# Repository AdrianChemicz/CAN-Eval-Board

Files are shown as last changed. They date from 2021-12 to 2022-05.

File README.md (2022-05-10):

# CAN Evaluation Board

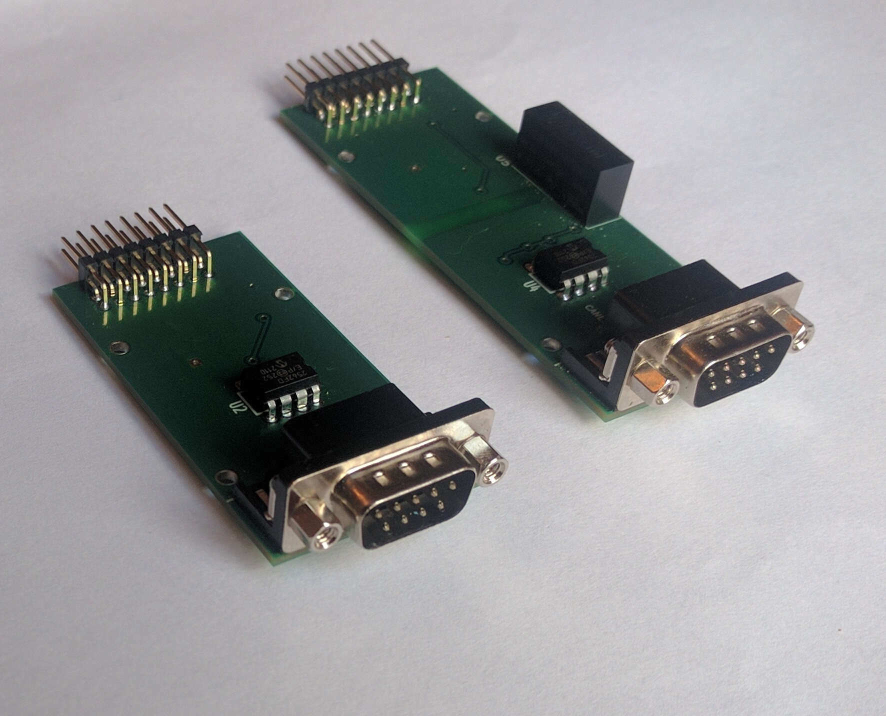
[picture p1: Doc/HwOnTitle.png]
Hardware on title
 <br />

CAN Evaluation Board is hardware project which provide evaluation board for CAN-FD. Evaluation board was prepared in two variant isolated and not isolated. Both variant use similar HW component like MCP2517FD and MCP2562FD chips. 

Device overview <br />

## 1.MCP2517FD

MCP2517FD is Microchip chip which work as SPI to CAN-FD converter. This chip provide also GPIO pins which can be configured via SPI and change state depending from situation like receive CAN message. Those GPIO pins was routed to connector CN1.<br /> 
On new design MCP2517FD chip is not recomended user should select MCP2518FD. Older driver should be compatible with this chip.

## 2.CAN transceiver

MCP2517FD chip to work with CAN network require CAN transceiver and for this purpose was chosen MCP2562FD chip in DIP8 package. Chip crisis cause that only this transceiver is available on market. This chip was optimaze for transfers up to 5 Mbps in CAN-FD mode.

## 3.Protection by isolation

Version of project which contain isolation to protect our system from high voltage on DB9 connector use DC/DC converter with galvanic separation to power CAN transceiver and optoisolation chip to separate CANTXD and CANRXD. As optoisolation was used MAX22245BAWA+ chip which add delay 43.7ns in worse case and allow to transmit signal with max transfer 25Mbps. Those parameters is very important because CAN controller during transmission via CANTX expect feeddback from transceiver on CANRX pin. Maximum delay between signal on pin CANTXD and CANRXD is equal 255ns. All things regarding optoisolation in CAN-FD systems was described in below document: <br />
[Meeting the Timing Requirements of CAN FD in Isolated CAN Systems for HEV/EVs](https://www.ti.com/lit/an/slla479/slla479.pdf) <br />

Delay on our system is also generated by PCB traces but this delay is very low (signal transmission speed is equal 6inch per ns). Equation about PCB signal delay is available on below page: <br />
[How to Calculate Trace Length from Time Delay Value for High-speed Signals](https://www.zuken.com/en/blog/how-to-calculate-trace-length-from-time-delay-value-for-high-speed-signals/) <br />

Worse case signal delay in our system was presented on below picture:
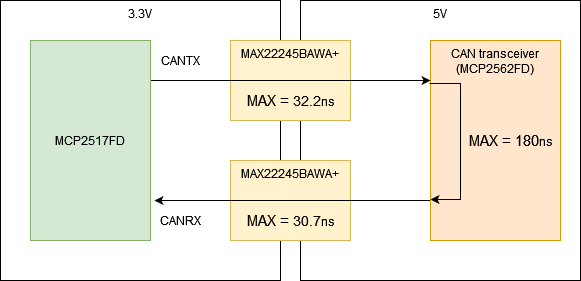
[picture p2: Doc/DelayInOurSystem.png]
Delay in our system
 <br />

In below table was presented typical and worse case signal propagation delay for all used electrical component.<br />
Electrical component | Typical propagation delay | Worse case propagation delay
------------ | ------------ | ------------
MAX22245BAWA+(Optoisolation chip) power from 3,3V | 23.4ns | 32.2ns
MAX22245BAWA+(Optoisolation chip) power from 5V | 22.6ns | 30.7ns
MCP2562FD(CAN transceiver) | 120ns | 180ns

Complete worse case propagation delay is equal:<br />
32.2ns + 30.7ns + 180ns = 242,9ns + small delay on traces which shouldn't exceed 1ns <br /><br />
In system was used two optoisolation chip instead one because selected chip transmit signal in one direction. Use bidirectional chip is very hard to find becauase chip crisis cause that many electrical component are unavailable on market. In project was used chip MAX22245BAWA+ which work only in single direction. Manufacturer Maxim Integrated offer similar chip but with bidirectional isolation this is marked as MAX22246BAWA+. Using this bidirectional chip PCB design will looks like better - one chip intead two.<br /><br />

To power chips on isolated part is used DC/DC converter with galvanic separation. In project was selected RFMM-0505S converter. This type of converter for correct operation require load on output so for this reason was used 470 ohm resistor(R3 on schematic).

## 4.Overal system design

On belew schematics was presented all parts of the system.

Version without optoisolation: <br />
Device without opto <br />
Version with optoisolation: <br />
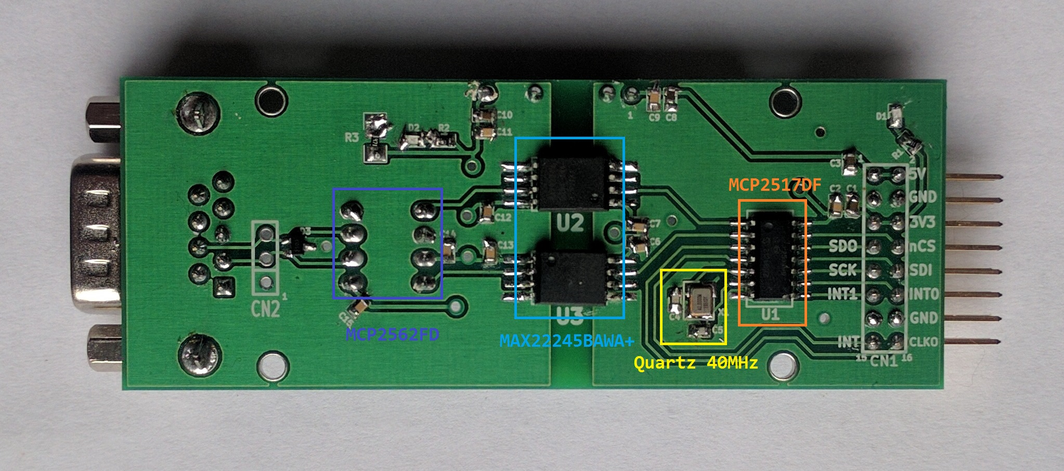
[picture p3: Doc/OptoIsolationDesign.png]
Device with opto
 <br />

On below pin header which is the same for two type of board with MCP2517FD chip exist two type of voltage input 3.3V and 5V. 3.3V input is used to power MCP2517FD chip and optoisolation module. 5V connector is used to power CAN transceiver. MCP2517FD chip and optoisolation module can correctly operate with 5V power suplly(MCP2517FD can operate in voltage range from 2,7V to 5,5Vs and MAX22245BAWA+ can operate in voltage range from 1,71V to 5,5V) so it mean that two power suply isn't necessary and can be reduced to single 5V power suply connected to 3V3 and 5V connectors. Connect 5V to 3V3 connector on board with MCP2517FD was tested on setup with LPC11U24 microcontroller and communication working correctly(CAN traffic was send correctly to bus). Used LPC11U24 during test was powered from 3,3V and work correctly with MCP2517FD because used microcontroller pins are 5V tolerant so communication will not damage microcontroler. 
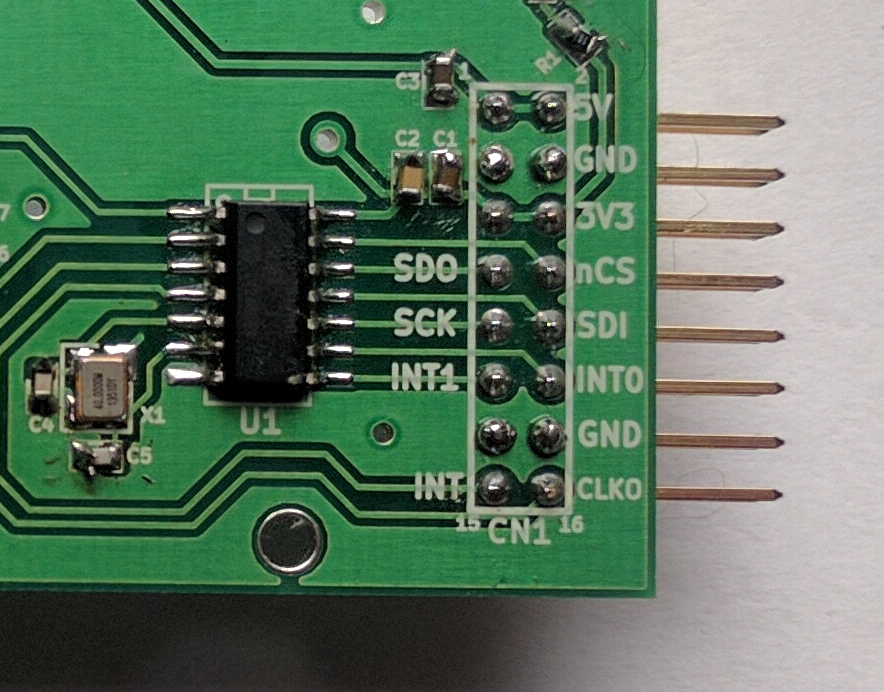
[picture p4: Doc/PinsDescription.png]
Pin header
 <br />

## 5.Project file

PCBs was designed in Kicad application and all files was added to appropriate project folders. In project folders also was added photos of PCB and PDF file with schematic. <br />
-board with optoisolation is available in below location: <br />
[CAN-FD optoisolated board](https://github.com/AdrianChemicz/CAN-Eval-Board/tree/main/CANFD_OptoIsolationBoardHardware) <br />
-board without optoisolation is available in below location: <br />
[CAN-FD board](https://github.com/AdrianChemicz/CAN-Eval-Board/tree/main/CANFD_BoardHardware) <br />

## 6.Software for MCP2517FD chip

### 6.1 Basic information
Microchip deliver example with library which can be very easly ported from microchip microcontroller to other microcontroller. From user perspective is only require to modify drv_spi.c file which contain access to SPI interface(only one file which depend from peripheral).

In drv_canfdspi_api.h header file we can find information "Subject to your compliance with these terms, you may use Microchip software and any derivatives exclusively with Microchip products." . According this paragraph I have doubt about legality usage of this library with MCP2517FD chip and NXP microcontrollers. Case was created on Microchip page and employee from Microchip answear that is only require use MCP2517xD chip with this driver and port to other microcontroller which belong to other manufacturer than microchip is legal.

Below I added links to microchip page with things for MCP2517FD chip: <br />
[-link to Microchip page with information about MCP2517FD](https://www.microchip.com/en-us/product/MCP2517FD) <br />
[-link to Microchip page with information about MCP2518FD which is recomended for new design](https://www.microchip.com/en-us/product/MCP2518FD) <br />
[-Link to source code example on Microchip page](https://ww1.microchip.com/downloads/en/DeviceDoc/MCP2517FD%20canfdspi%20API%20for%20SAMV71%20(v1.0).zip) <br /><br />
Complete port process of microchip library to other microcontroller require from user few steps and below all necessary things was described:<br />

1)From link section in this chapter please download SW example from mmicrochip page and copy "driver" directory from folder "MCP2517FD canfdspi API for SAMV71 (v1.0).zip\V71_CANFDSPI\V71_CANFDSPI" to new project directory.<br />
2)In \driver\spi\drv_spi.c modify below things:<br />
a)Modify function spi_master_init(void) which initialize microcontroller SPI port.<br />
a)modify function spi_master_transfer(...) which send data via microcontroller SPI port.<br />
c)modify #include section to keep only necessary things and include file with driver to used microcontroller.<br />
d)modify #define section to don't keep not used things.<br /><br />

In [SW directory](https://github.com/AdrianChemicz/CAN-Eval-Board/tree/main/SW)
 was provided examples for three LPC microcontrollers(MCP2517FD_ExampleFor_LPC111X, MCP2517FD_ExampleFor_LPC11UXX and MCP2517FD_ExampleFor_LPC82X). In those three examples most of code operate just on microchip API not on microntrollers peripherals. Provided code only use systick as timer which is common for all cortex-MX microcontrolers and can be very easy ported to other ARM microcontrollers. In those three provided example micirochip API is called from [MCP2517FD_ExampleFor_LPC111X.c](https://github.com/AdrianChemicz/CAN-Eval-Board/blob/main/SW/MCP2517FD_ExampleFor_LPC111X/src/MCP2517FD_ExampleFor_LPC111X.c), [MCP2517FD_ExampleFor_LPC11UXX.c](https://github.com/AdrianChemicz/CAN-Eval-Board/blob/main/SW/MCP2517FD_ExampleFor_LPC11UXX/src/MCP2517FD_ExampleFor_LPC11UXX.c) and [MCP2517FD_ExampleFor_LPC82X.c](https://github.com/AdrianChemicz/CAN-Eval-Board/blob/main/SW/MCP2517FD_ExampleFor_LPC82X/src/MCP2517FD_ExampleFor_LPC82X.c) files(single file per example). In provided examples is possible to prepare test of SPI interface without connected MPC2517FD chip. If physical connection with chip will be missing then SPI communication with chip will be not suspended by example. Using this feature in provided examples was added below code:
>#if 0 //SPI protocol debug code<br />
>	{<br />
>		uint8_t testedWritePayload[8] = {46, 5, 124, 119, 122, 9, 87, 234};<br />
>		uint8_t readPayload[8] = {0, 0, 0, 0, 0, 0, 0, 0};<br />
>		// Write data to RAM<br />
>		DRV_CANFDSPI_WriteByteArray(DRV_CANFDSPI_INDEX_0, cRAMADDR_START, testedWritePayload, 8);<br />
><br />
>		// Read data back from RAM<br />
>		DRV_CANFDSPI_ReadByteArray(DRV_CANFDSPI_INDEX_0, cRAMADDR_START, readPayload, 8);<br />
><br />
>		Nop();<br />
>	}<br />
>#endif<br />

Using this part of code user can verify that SPI work correctly by own SPI traffic with below log.<br /> 
Function DRV_CANFDSPI_WriteByteArray in debug code will cause that ganerated SPI traffic will be similar like this traffic below:
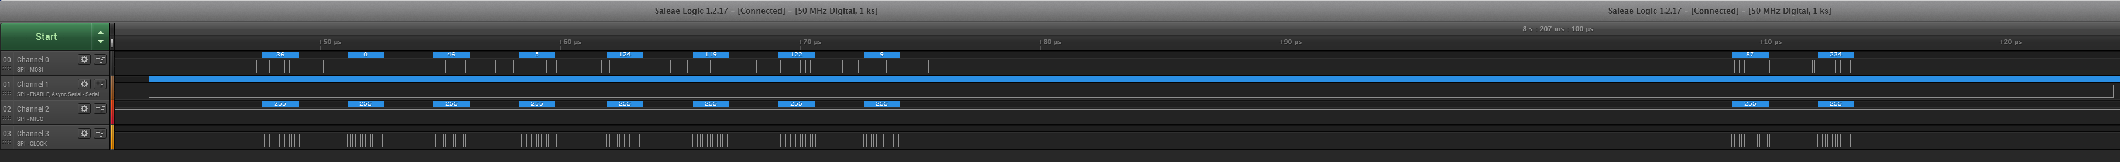
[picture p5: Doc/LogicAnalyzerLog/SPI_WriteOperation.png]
SPI write

Function DRV_CANFDSPI_ReadByteArray in debug code with correctly connected and configured MCP2517FD chip will cause that ganerated SPI traffic will be similar like this traffic below:
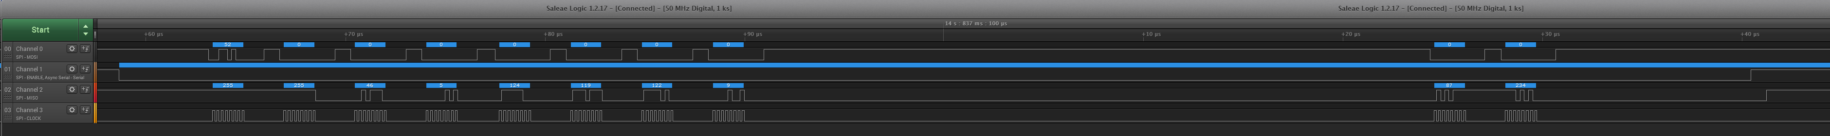
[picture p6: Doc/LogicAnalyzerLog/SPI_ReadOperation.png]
SPI read


Below was added SPI setting from Saleae logic analyzer used during decode data:
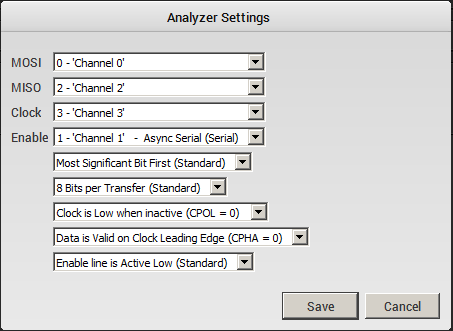
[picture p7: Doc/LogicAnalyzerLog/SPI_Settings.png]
SPI settings


In [directory with SPI screenshots](https://github.com/AdrianChemicz/CAN-Eval-Board/tree/main/Doc/LogicAnalyzerLog) was added log gather via Saleae logic analyzer in binary format and CSV file.

### 6.2 Code examples

In [SW directory](https://github.com/AdrianChemicz/CAN-Eval-Board/tree/main/SW) was provided few examples which can be directly imported to LPCXpresso. To setup complete working environment source code is not enough. To provide fully working environment is required microcontroller eval board connected to board with MCP2517FD so in this chapter was described connections between those two boards and other usefull information related to hardware.

#### 6.2.1 LPC82X example

In this example during test was used dedicated board which is available [here](https://github.com/AdrianChemicz/CAN-Eval-Board/tree/main/LPC82X_EvalBoard). LPC8X microcontroller family contain switch matrix which allow move peripheral functionality to one of available GPIO pins. This feature allow user to configure microcontroller pins in way which simplify connection with other hardware. LPC8X microcontroller board contain FT234XD chip which can be used to comunicate with PC using virtual COM port. <br />

Below was added picture how to connect two board:
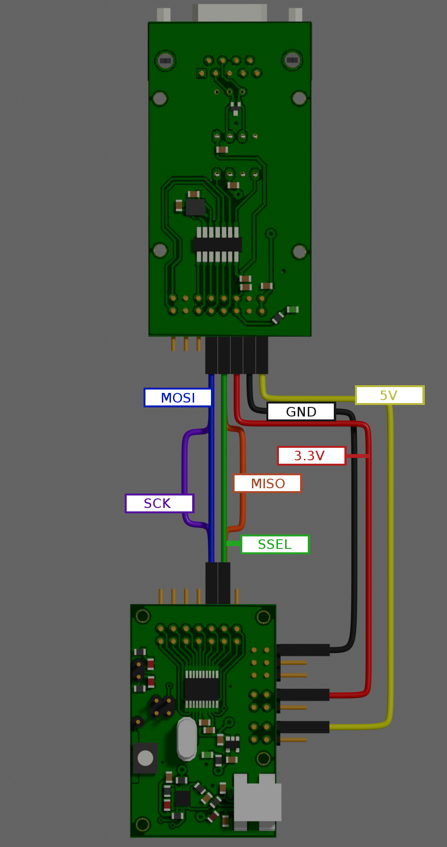
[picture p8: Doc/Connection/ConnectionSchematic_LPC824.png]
LPC82X Connection

Pin connection table:
Connection name | MCP2517FD board | LPC82X board
------------ | ------------ | ------------
SSEL | CN1.8 nCS | CN5.12 PIO0_23/ADC_3/ACMP_I4
SCK | CN1.9 SCK | CN5.9 PIO0_12
MOSI | CN1.10 SDI | CN5.10 PIO0_13/ADC_10
MISO | CN1.7 SDO | CN5.11 PIO0_17/ADC_9
5V | CN1.2 5V | CN2 5V
3.3V | CN1.6 3V3 | CN3 3V3
GND | CN1.4 GND | CN4 GND

Photo with connected two board is available [here](/Doc/LPC82X_Connection.png).

#### 6.2.2 LPC11XX example

In this example during test was used board [OM11049](https://eu.mouser.com/ProductDetail/NXP-Semiconductors/OM11049598?qs=gr1fGwdOAsJfB09qfdGFmA%3D%3D). This board isn't available in sale - it was replaced by [OM13035](https://www.nxp.com/design/microcontrollers-developer-resources/lpcxpresso-board-for-lpc1115:OM13035). Main difference between OM11049 and OM13035 was changed microcontroller from LPC1114 to LPC1115. On OM13035 page PDF file with electrical schematic is the same like in OM11049 so it mean that microntroller pins location wasn't changed. Currently OM13035 also wasn't available in sale - was replaced by [OM13087](https://www.nxp.com/products/processors-and-microcontrollers/arm-microcontrollers/general-purpose-mcus/lpc1100-cortex-m0-plus-m0/lpcxpresso-board-for-lpc1115-with-cm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). Old and new board was compared and pins location on target side(LPC111X microcontroller side) between version wasn't changed. Only major differences between those two boards it is additional LED in new version of board(OM13087). OM11049 board don't provide 5V power source so to provide necessary voltage was used additional power source.<br />

Below was added picture how to connect two board:
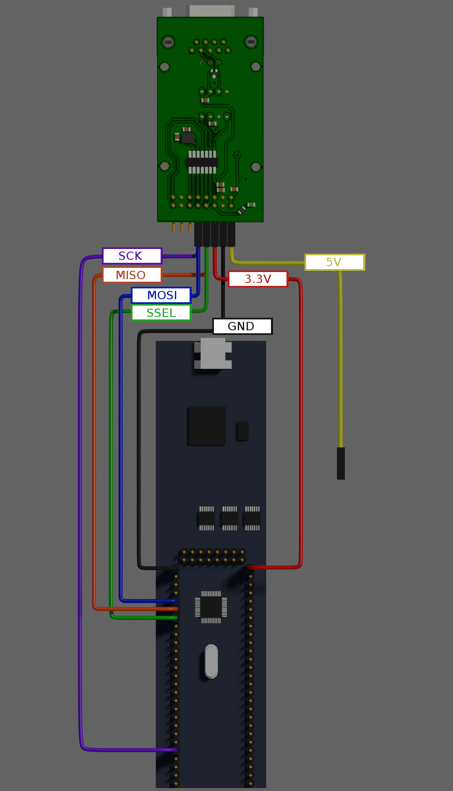
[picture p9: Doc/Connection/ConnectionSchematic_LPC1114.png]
LPC111X Connection

Pin connection table:
Connection name | MCP2517FD board | OM11049 board
------------ | ------------ | ------------
SSEL | CN1.8 nCS | J6.7 PIO2_11/SCK0/CT32B0_CAP1
SCK | CN1.9 SCK | J6.23 PIO0_6/SCK0
MOSI | CN1.10 SDI | J6.5 PIO0_9/MOSI0/CT16B0_MAT1
MISO | CN1.7 SDO | J6.6 PIO0_8/MISO0/CT16B0_MAT0
5V | CN1.2 5V | ---
3.3V | CN1.6 3V3 | J6.28 3V3
GND | CN1.4 GND | J6.1 GND

Photo with connected two board is available [here](/Doc/LPC1114_Connection.png).

#### 6.2.3 LPC11UXX example

In this example during test was used dedicated board which is available [here](https://github.com/AdrianChemicz/FootController/tree/main/PCB). In this board used LPC11U24 microcontroller.<br />

Below was added picture how to connect two board:
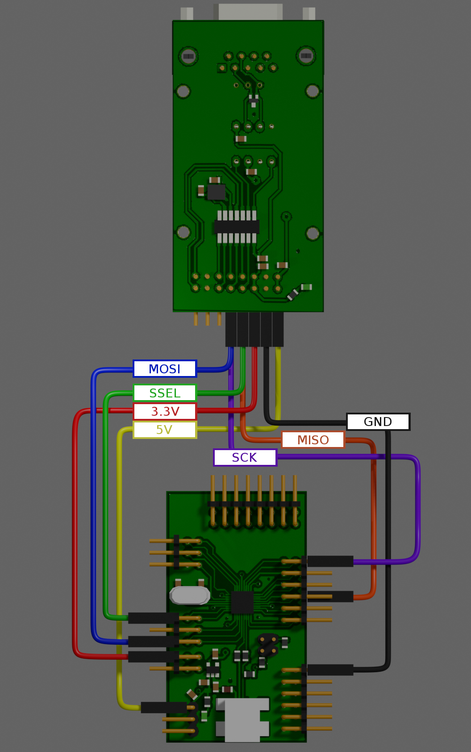
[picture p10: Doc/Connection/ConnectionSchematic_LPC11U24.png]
LPC11UXX Connection

Pin connection table:
Connection name | MCP2517FD board | LPC11UXX board
------------ | ------------ | ------------
SSEL | CN1.8 nCS | CN5.5 PIO0_2/SSEL0/CT16B0_CAP0
SCK | CN1.9 SCK | CN7.1 PIO1_15/DCD/CT16B0_MAT2/SCK1
MOSI | CN1.10 SDI | CN5.1 PIO0_21/CT16B1_MAT0/MOSI1
MISO | CN1.7 SDO | CN7.8 PIO0_22/AD6/CT16B1_MAT1/MISO1
5V | CN1.2 5V | CN3 5V
3.3V | CN1.6 3V3 | CN4 3V3
GND | CN1.4 GND | CN2 GND

Photo with connected two board is available [here](/Doc/LPC11U24_Connection.png).

## 7.Other MCP2517FD chip hardware

In case when user would like to fast start prototype SW with real hardware then build own hardware isn't necessary. On market are provided solutions like this - [MCP2517FD click](https://www.mikroe.com/mcp2517fd-click). This board use product ID MIKROE-2379 and according this number can be found on [farnell](https://pl.farnell.com/mikroelektronika/mikroe-2379/can-fd-controller-click-board/dp/2858076?ost=mikroe-2379) or on [TME](https://www.tme.eu/pl/details/mikroe-2379/plytki-rozszerzajace/mikroelektronika/mcp2517fd-click/).

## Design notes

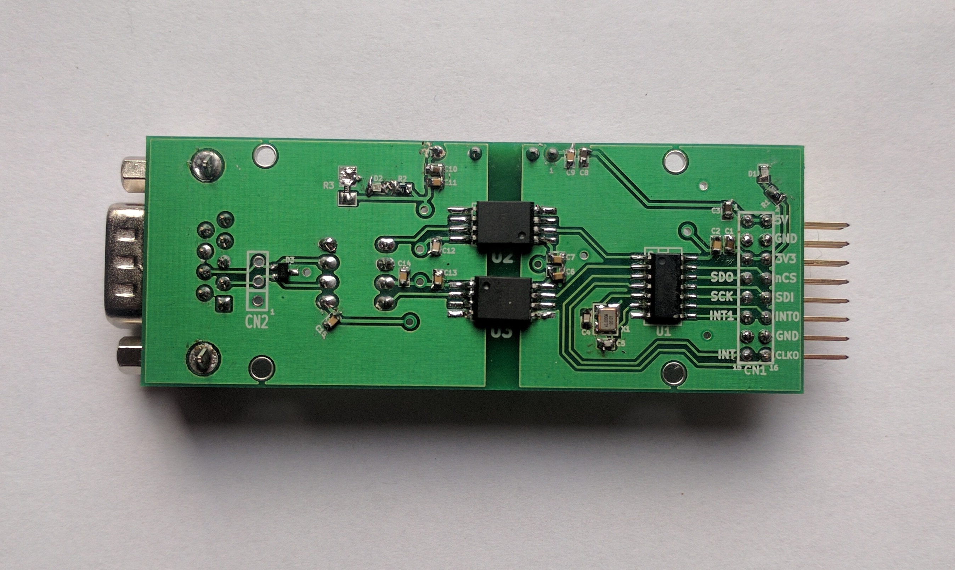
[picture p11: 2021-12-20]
CANFD_OptoIsolationBoardHardware/OptoIsolationBoardBottomPart.jpg

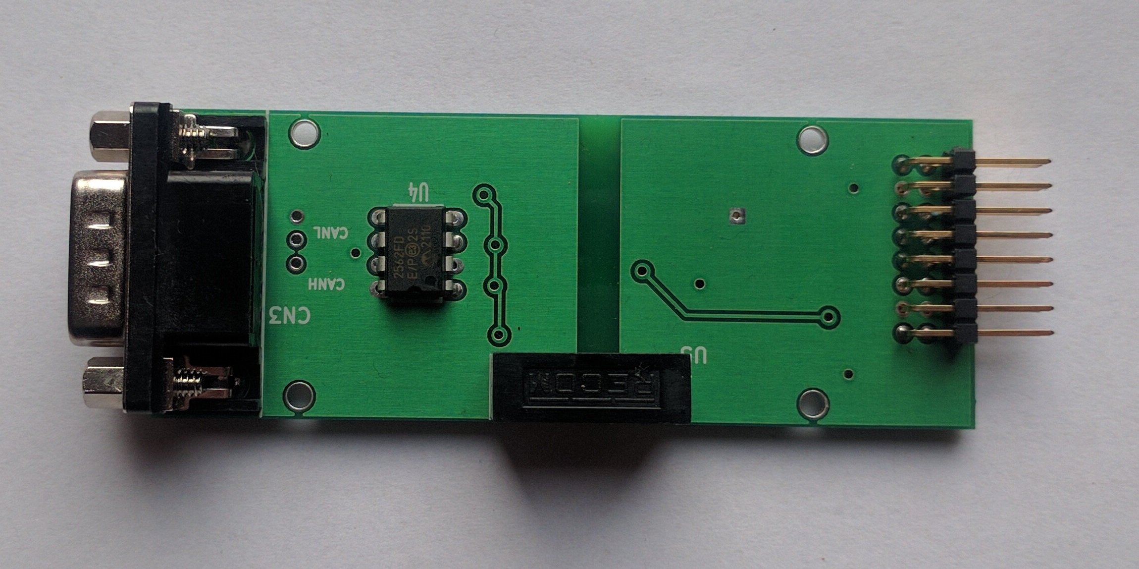
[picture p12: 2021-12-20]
CANFD_OptoIsolationBoardHardware/OptoIsolationBoardUpperPart.jpg

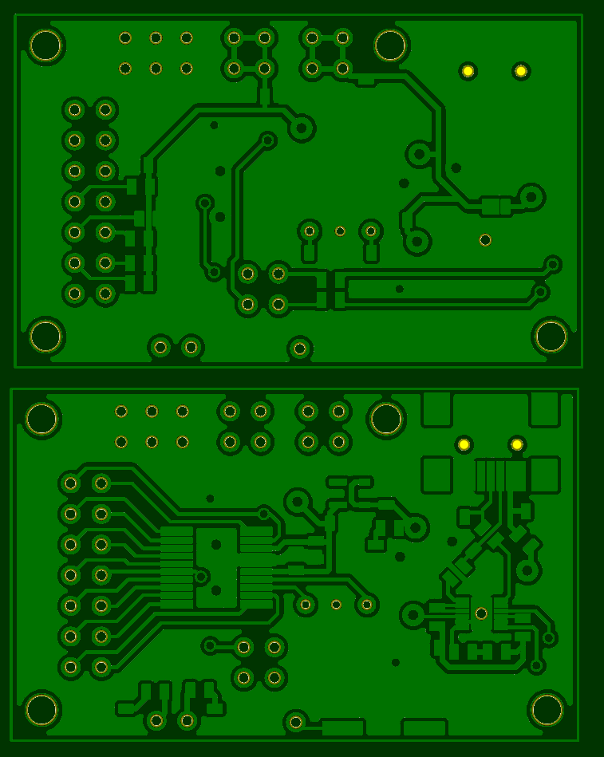
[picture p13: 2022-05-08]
Doc/Blender/PCB_Blender8.png

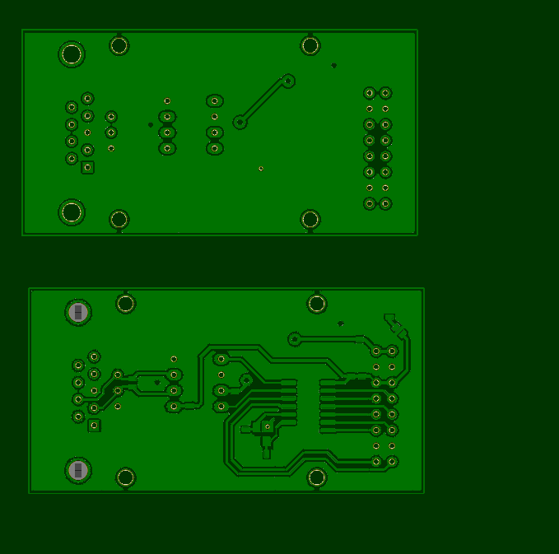
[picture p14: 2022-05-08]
Doc/Blender/PCB_Blender6.png

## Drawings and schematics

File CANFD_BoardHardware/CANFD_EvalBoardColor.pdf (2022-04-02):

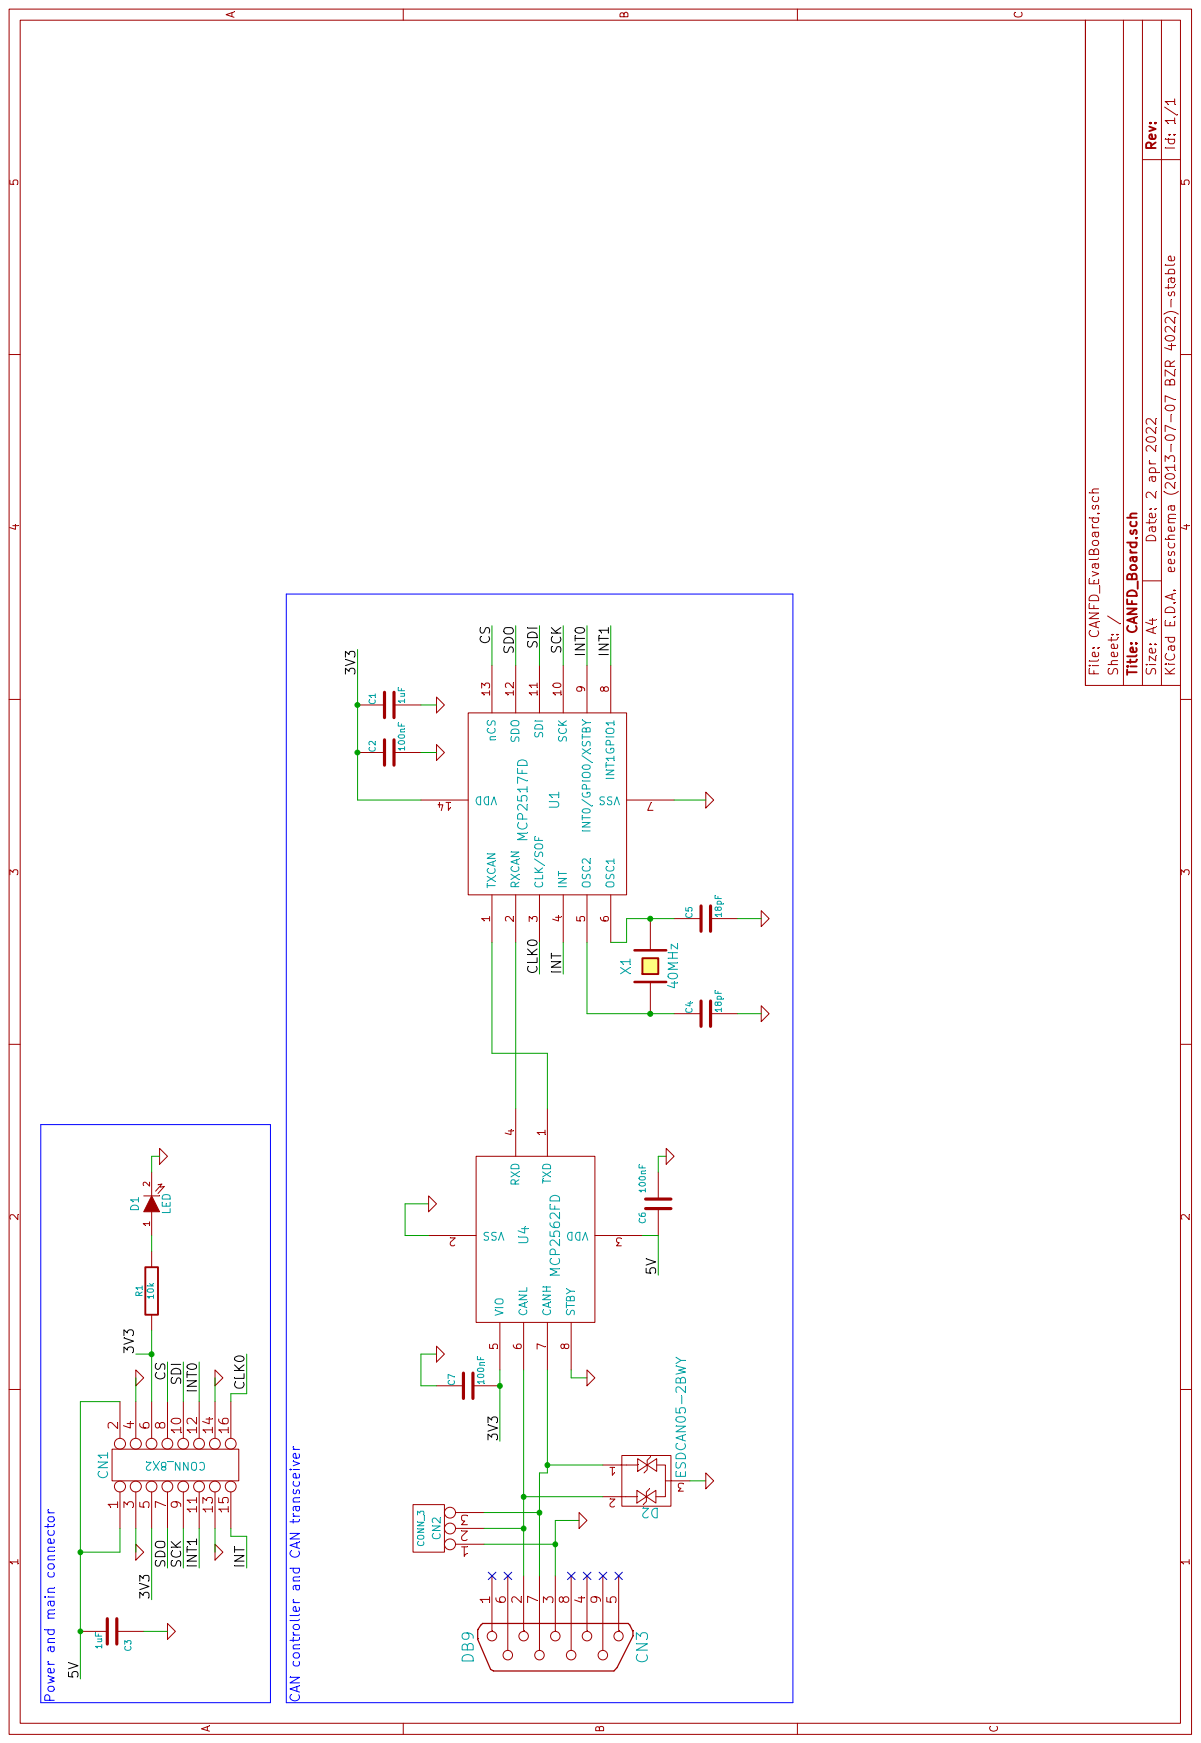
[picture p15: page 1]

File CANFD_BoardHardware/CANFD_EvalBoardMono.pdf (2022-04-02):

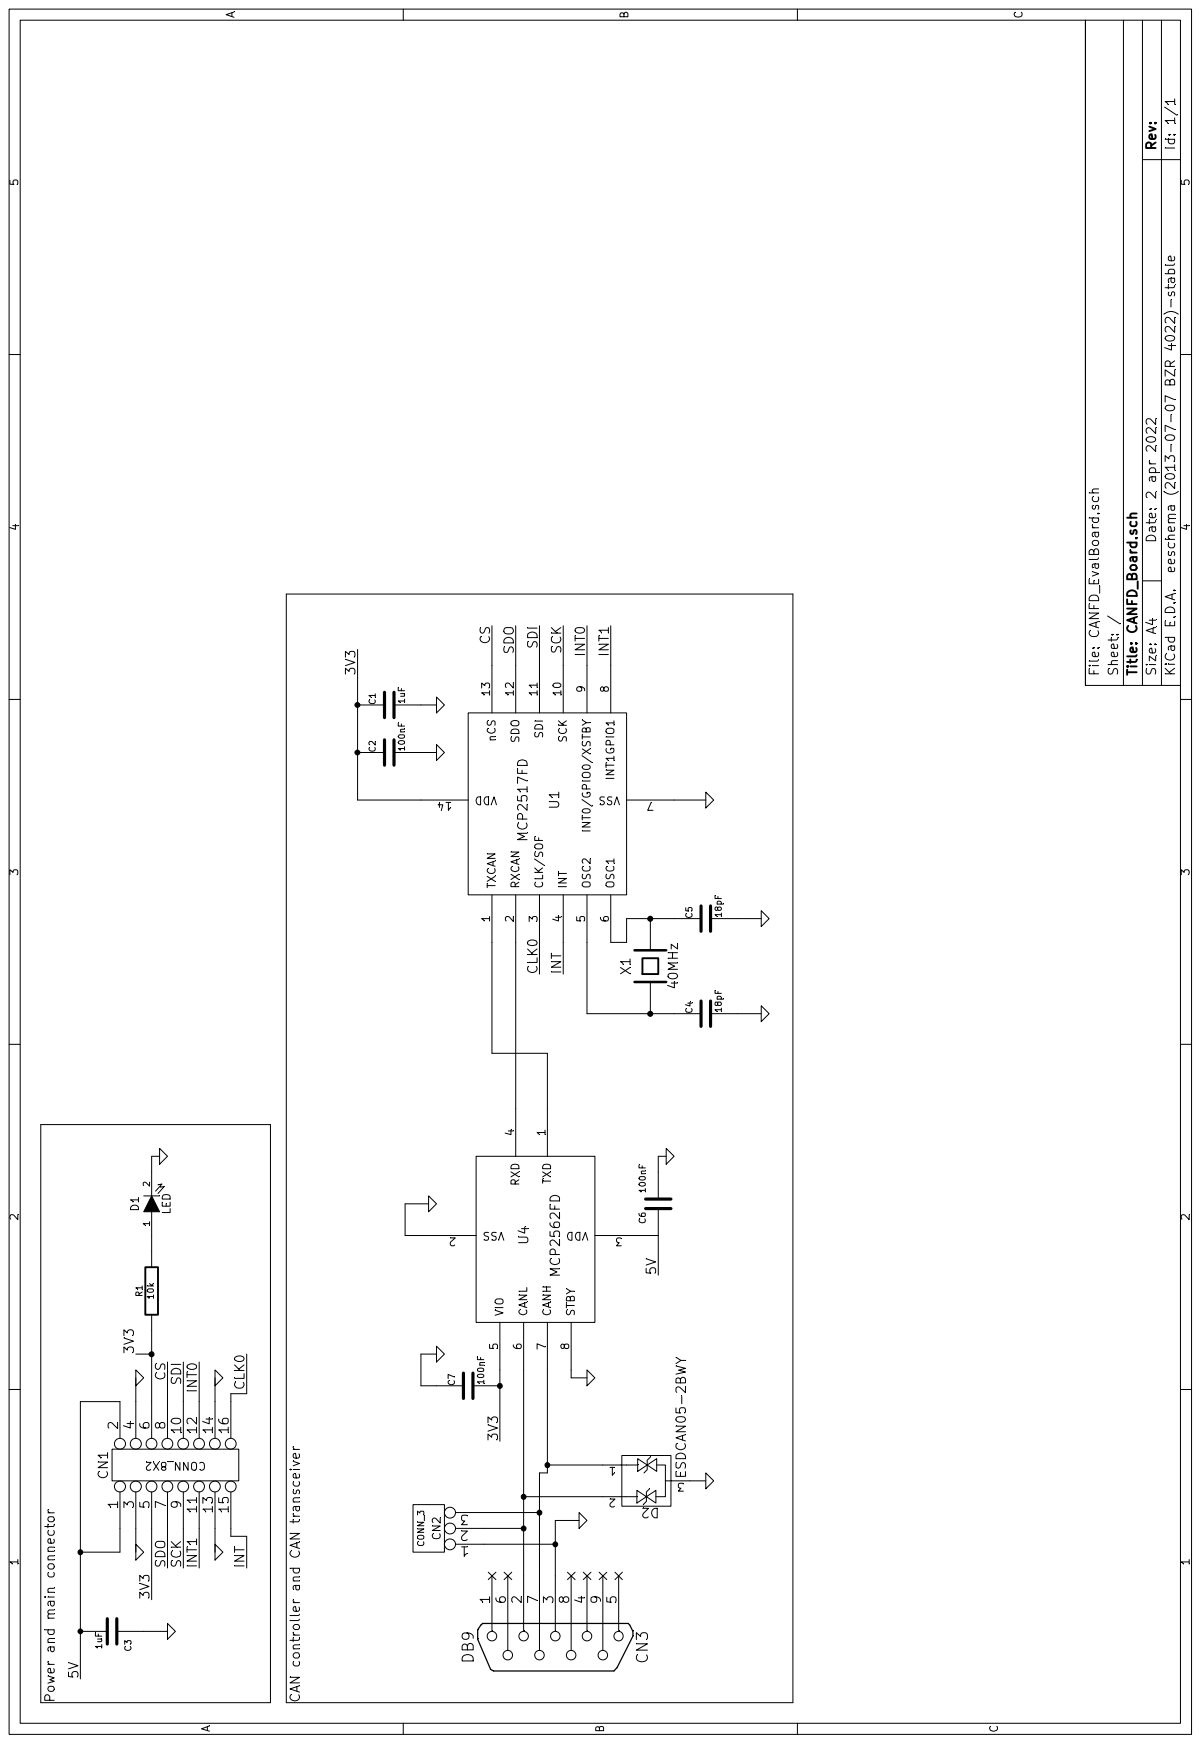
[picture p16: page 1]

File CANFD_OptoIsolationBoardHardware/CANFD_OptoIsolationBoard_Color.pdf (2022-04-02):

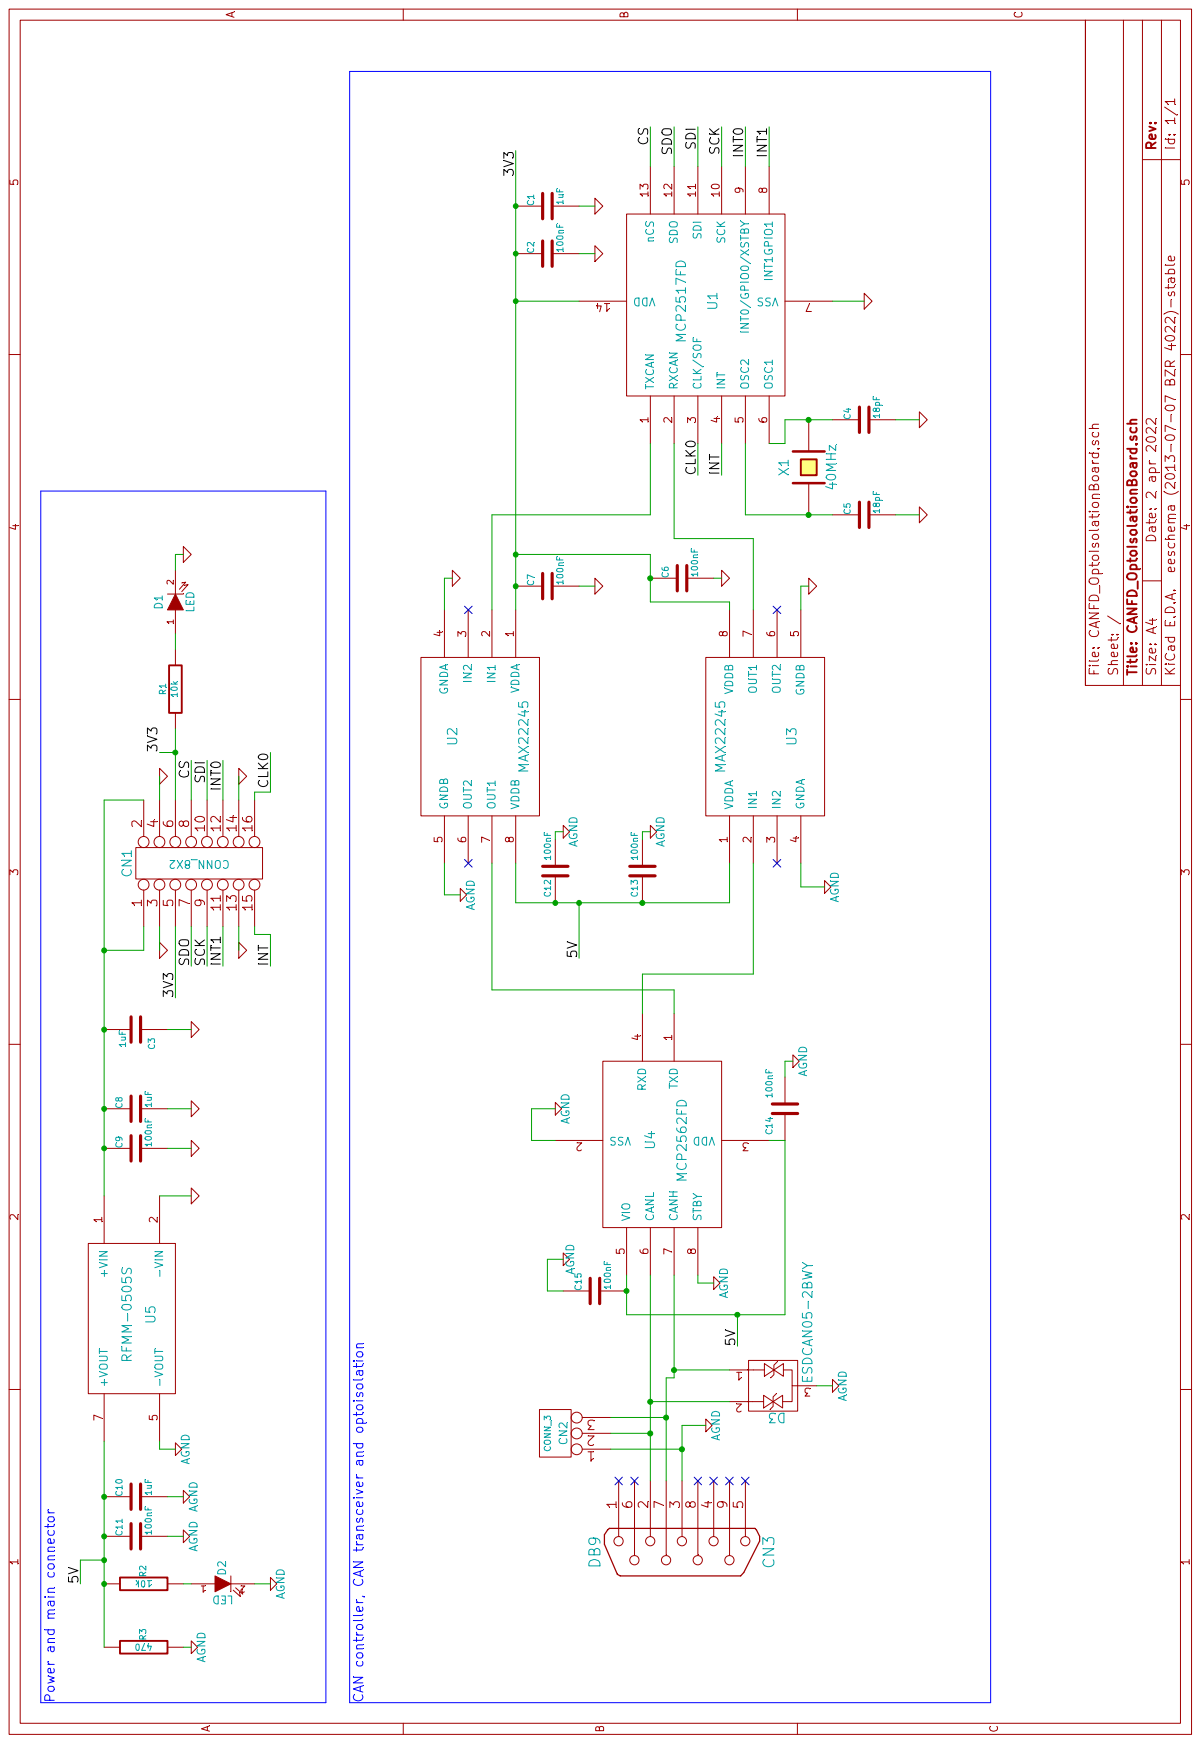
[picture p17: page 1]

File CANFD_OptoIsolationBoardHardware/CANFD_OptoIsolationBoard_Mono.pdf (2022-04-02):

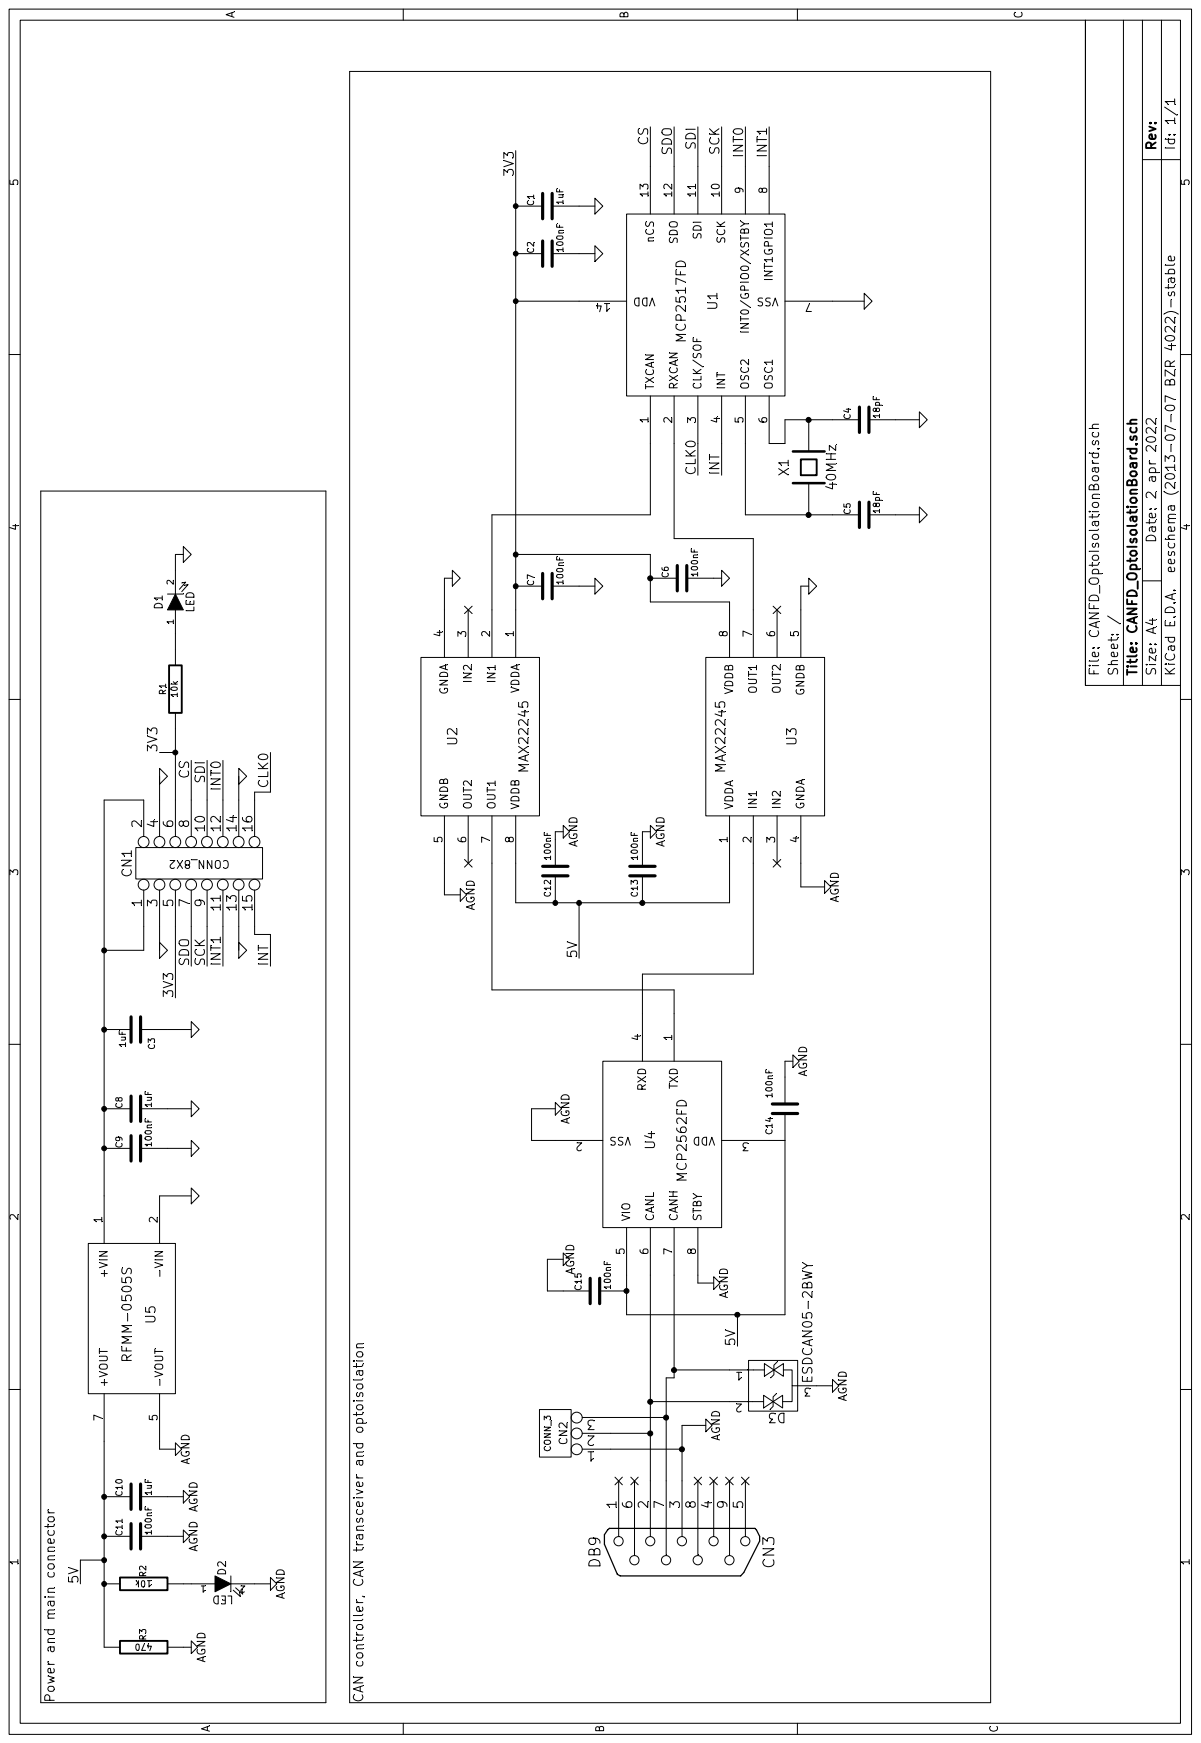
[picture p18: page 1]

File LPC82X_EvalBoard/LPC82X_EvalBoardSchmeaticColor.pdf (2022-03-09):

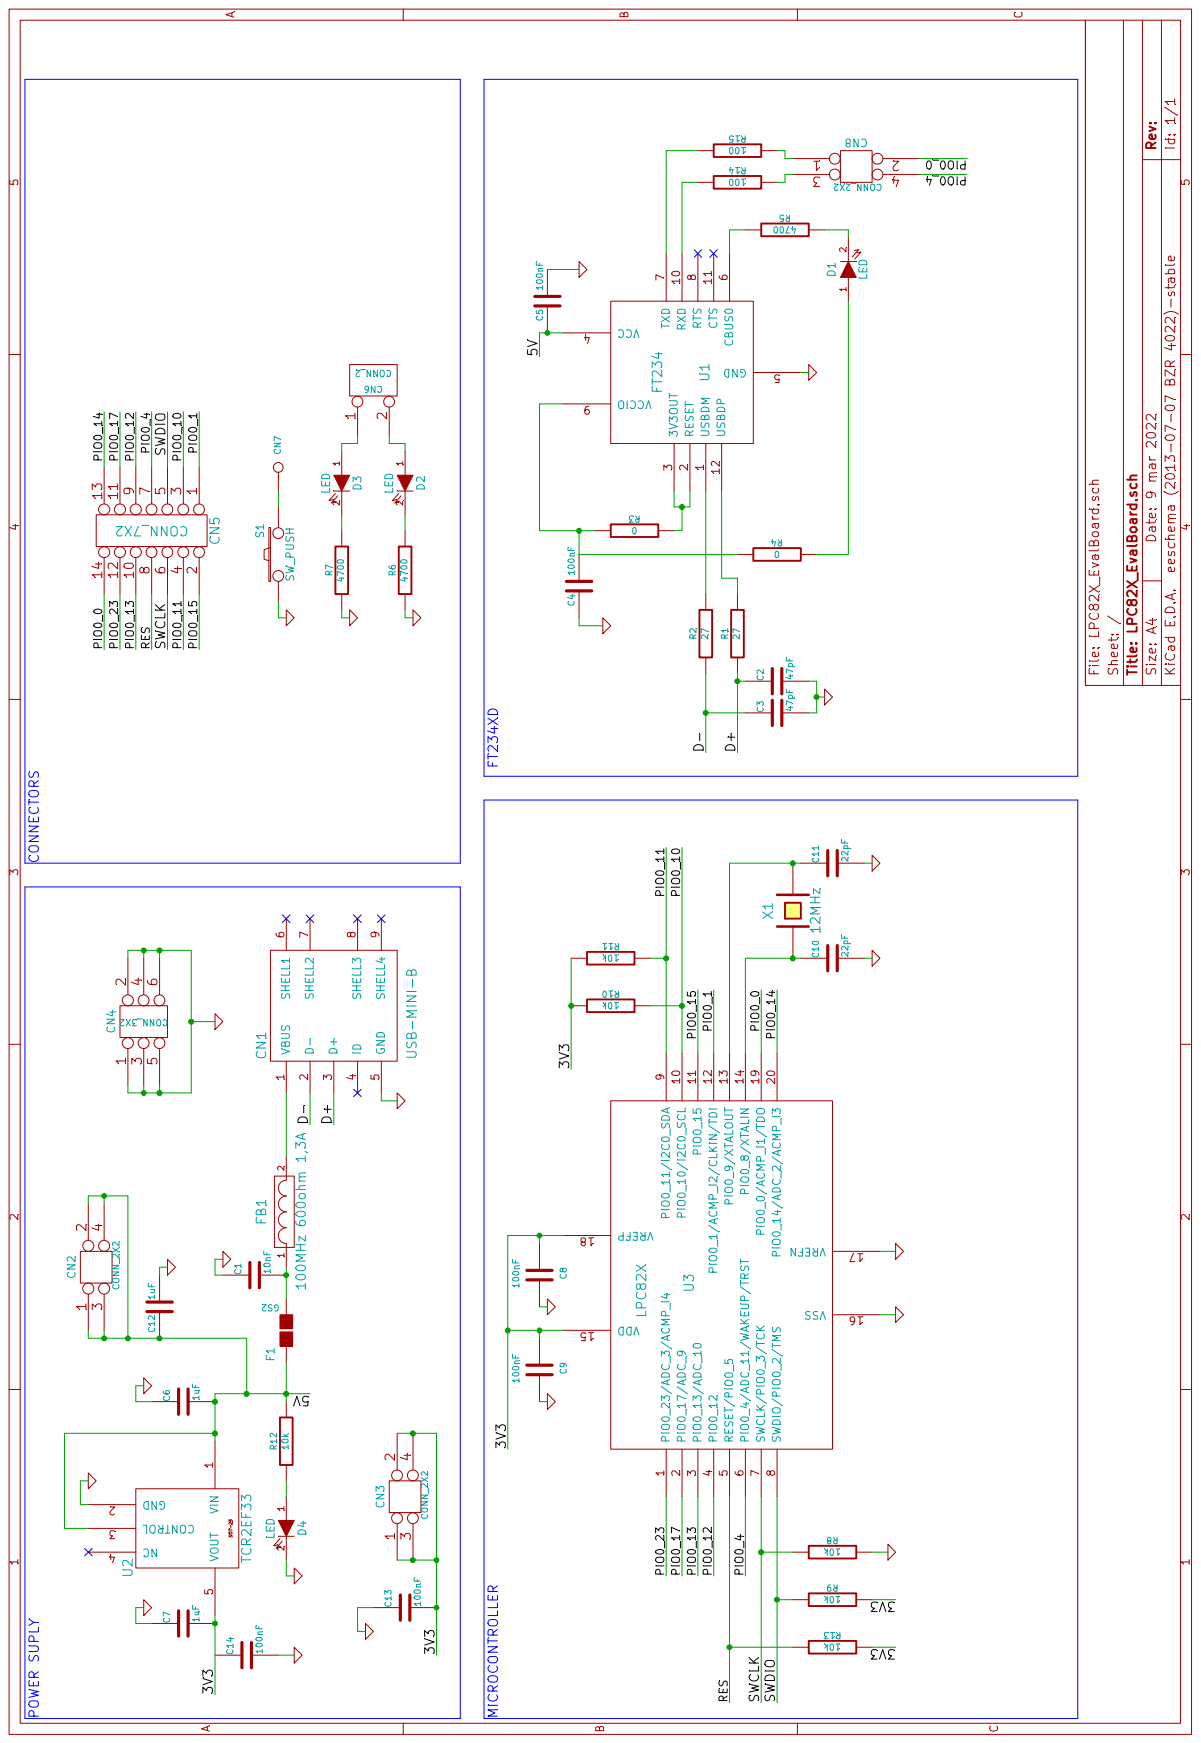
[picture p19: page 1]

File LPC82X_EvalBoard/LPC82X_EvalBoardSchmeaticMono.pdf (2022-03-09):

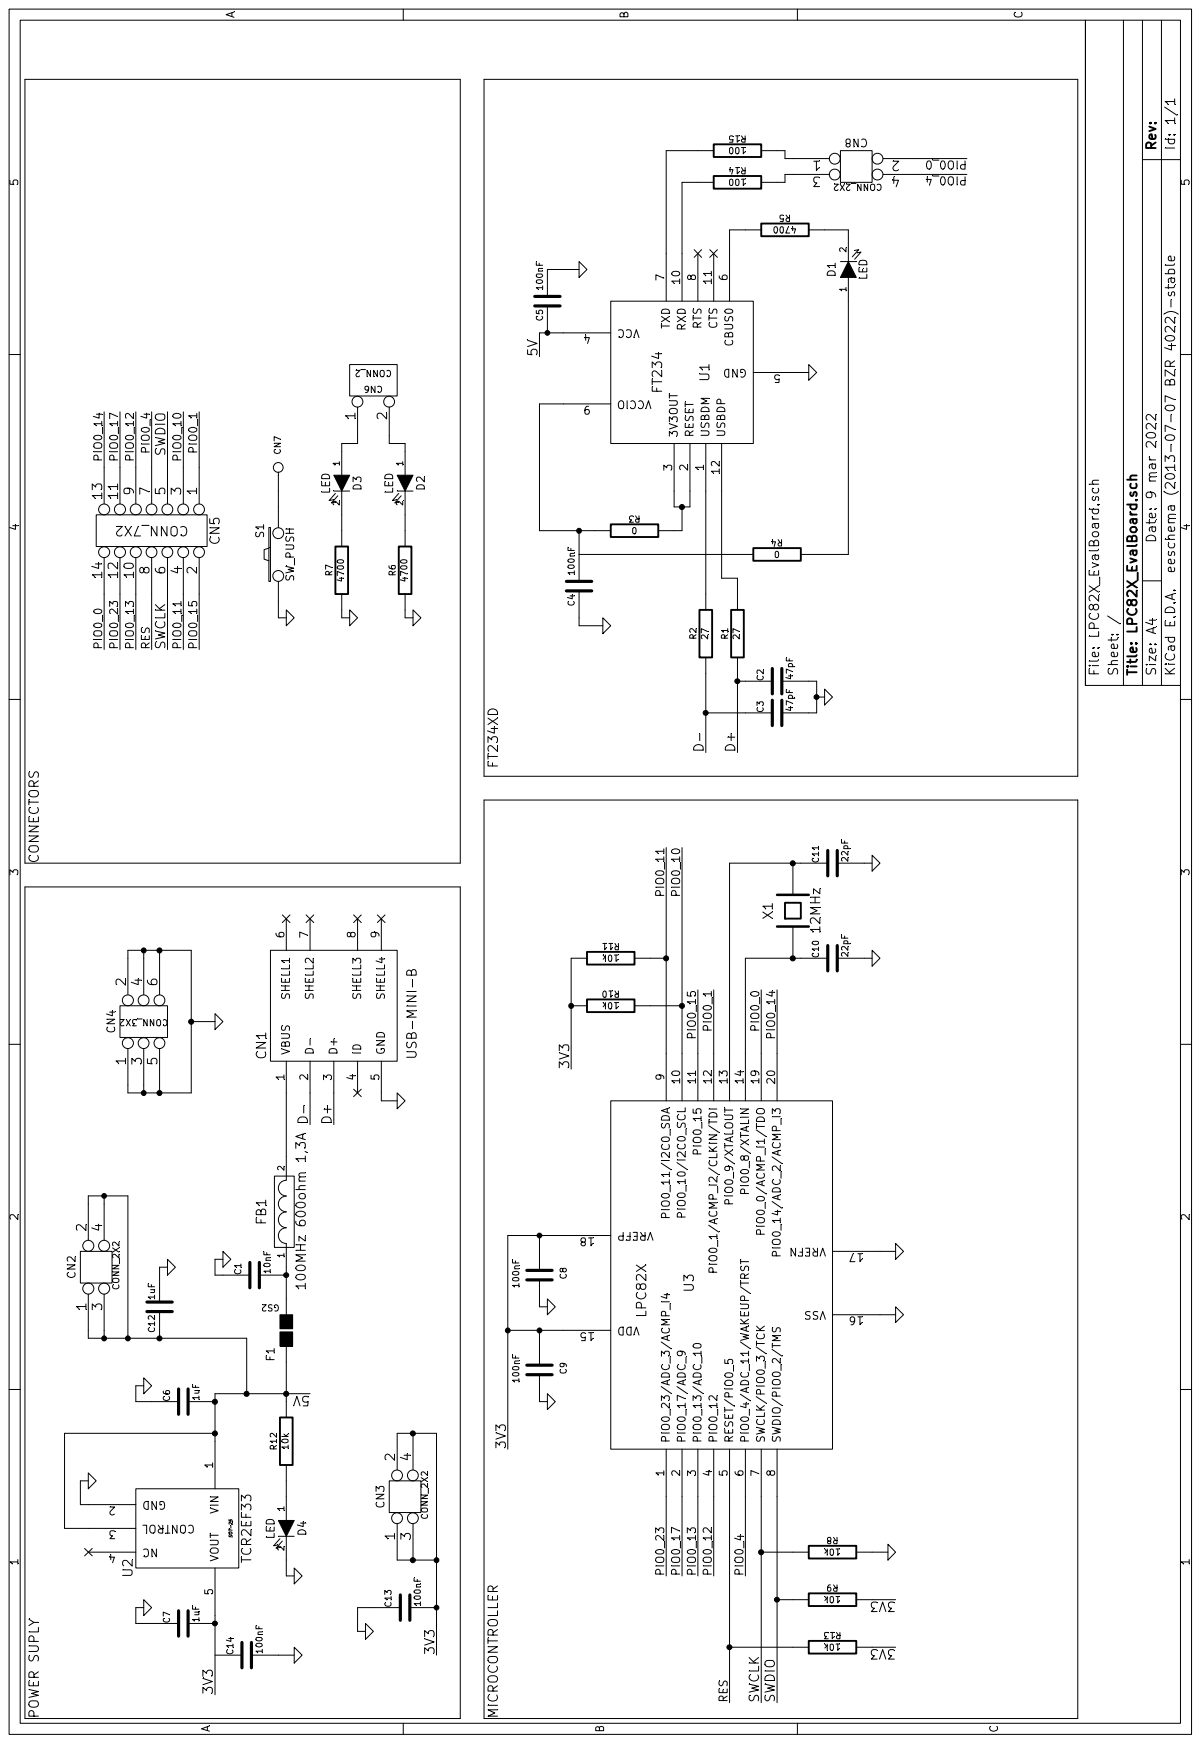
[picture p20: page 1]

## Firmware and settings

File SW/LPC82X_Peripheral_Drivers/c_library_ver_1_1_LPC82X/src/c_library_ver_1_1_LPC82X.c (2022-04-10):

/*
* Copyright (c) 2022, Adrian Chemicz
* All rights reserved.
*
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
* THIS SOFTWARE IS PROVIDED BY THE COPYRIGHT HOLDERS AND CONTRIBUTORS "AS IS" AND
* ANY EXPRESS OR IMPLIED WARRANTIES, INCLUDING, BUT NOT LIMITED TO, THE IMPLIED
* WARRANTIES OF MERCHANTABILITY AND FITNESS FOR A PARTICULAR PURPOSE ARE
* DISCLAIMED. IN NO EVENT SHALL COPYRIGHT HOLDER BE LIABLE FOR ANY
* DIRECT, INDIRECT, INCIDENTAL, SPECIAL, EXEMPLARY, OR CONSEQUENTIAL DAMAGES
* (INCLUDING, BUT NOT LIMITED TO, PROCUREMENT OF SUBSTITUTE GOODS OR SERVICES;
* LOSS OF USE, DATA, OR PROFITS; OR BUSINESS INTERRUPTION) HOWEVER CAUSED AND
* ON ANY THEORY OF LIABILITY, WHETHER IN CONTRACT, STRICT LIABILITY, OR TORT
* (INCLUDING NEGLIGENCE OR OTHERWISE) ARISING IN ANY WAY OUT OF THE USE OF THIS
* SOFTWARE, EVEN IF ADVISED OF THE POSSIBILITY OF SUCH DAMAGE.
*/

#include <cr_section_macros.h>
#include <stdbool.h>
#include <stdint.h>

#include "GPIO_Driver.h"
#include "UART_Driver.h"
#include "SPI_Driver.h"
#include "I2C_Driver.h"

/*
* Purpose of this application is to test all peripheral supported by this library like
* GPIO, UART, SPI and I2C. In this example clock source can be changed from IRC to PLL
* which operate on external quartz. During test tested board was used with 12MHz quartz
* and core is clocked with 24MHz but UART was cloced with 48MHz which provide 3MBaud.
*/

void ClockSleep(uint32_t time)
{
#if 1 //good value for 12MHz // for 1ms wait is equal 1,89ms tested under logic analyzer
	for (volatile uint32_t count = 0; count < (uint32_t)(time<<11);)
#endif
#if 0 //good value for 48MHz
	for (volatile uint32_t count = 0; count < (uint32_t)(time<<13);)
#endif
	{
		 count++;
	}
}

void ClockChangeFrequency(void)
{
	// Set system main clock divider
	LPC_SYSCON->SYSAHBCLKDIV  = 2;

#if 1 //Code for XTAL oscilator
	// Enable IOCON block
	LPC_SYSCTL->SYSAHBCLKCTRL |= (1<<18);

	/* Disable pullup/pulldown resistor for pin PIO0_8/XTALIN
	 * In IOCON->PIO0 registers pin number can't be use as index
	 * because table index not mean pin number. Element 0 is PIO0_17,
	 * element 1 is PIO0_13, element 2 is PIO0_12. */
	LPC_IOCON->PIO0[14] &= ~PIN_MODE_MASK;

	/* Disable pullup/pulldown resistor for pin PIO0_9/XTALOUT
	 * In IOCON->PIO0 registers pin number can't be use as index
	 * because table index not mean pin number. Element 0 is PIO0_17,
	 * element 1 is PIO0_13, element 2 is PIO0_12. */
	LPC_IOCON->PIO0[13] &= ~PIN_MODE_MASK;

	// Enable clock for switch matrix
	LPC_SYSCTL->SYSAHBCLKCTRL |= (1<<7);

	// Activate XTALIN function for PIO0_8/XTALIN pin
	LPC_SWM->PINENABLE0 &= ~(1<<6);

	// Activate XTALOUT function for PIO0_9/XTALOUT pin
	LPC_SWM->PINENABLE0 &= ~(1<<7);

	//Power-up System Osc
	LPC_SYSCON->PDRUNCFG &= ~(1<<5);

	//Configure system oscilator to work standard quartz and with quart with frequency range 1 MHz-20 MHz
	LPC_SYSCON->SYSOSCCTRL = 0;

	ClockSleep(1);

	/* Select PLL Input      1=System oscillator. Crystal Oscillator (SYSOSC)
	   0x0 IRC */
	LPC_SYSCON->SYSPLLCLKSEL = 1;
#else
	/* Select PLL Input      1=System oscillator. Crystal Oscillator (SYSOSC)
	   0x0 IRC */
	LPC_SYSCON->SYSPLLCLKSEL = 0;
#endif

	LPC_SYSCON->SYSPLLCLKUEN  = 0x01;               /* Update Clock Source      */
	LPC_SYSCON->SYSPLLCLKUEN  = 0x00;               /* Toggle Update Register   */
	LPC_SYSCON->SYSPLLCLKUEN  = 0x01;

	// Wait Until Updated
	while (!(LPC_SYSCON->SYSPLLCLKUEN & 0x01));

	// Power-up SYSPLL
	LPC_SYSCON->SYSPLLCTRL = 0x23;

	// Power-up PLL
	LPC_SYSCON->PDRUNCFG &= ~(1<<7);

	// Wait Until PLL Locked
	while (!(LPC_SYSCON->SYSPLLSTAT & 0x01));

	LPC_SYSCON->MAINCLKSEL    = 3;     /* Select PLL Clock Output  */
	LPC_SYSCON->MAINCLKUEN    = 0x01;  /* Update MCLK Clock Source */
	LPC_SYSCON->MAINCLKUEN    = 0x00;  /* Toggle Update Register   */
	LPC_SYSCON->MAINCLKUEN    = 0x01;

	// Wait Until Updated
	while (!(LPC_SYSCON->MAINCLKUEN & 0x01));
}

int main(void) {

	GPIO_Init();

#if 1
	//check work microcontroller with active PLL
	{
		volatile bool changeFrequency = false;

		if (changeFrequency)
		{
			ClockChangeFrequency();
		}
	}
#endif

#if 1
	//GPIO test
	{
		volatile bool changeGpio = false;

		if (changeGpio)
		{
			GPIO_Direction(0, 0, GPIO_DIR_OUTPUT);
			GPIO_SetState(0, 0, false);
			GPIO_SetState(0, 0, true);
			GPIO_SetState(0, 0, false);
			GPIO_SetState(0, 0, true);

			for (bool stateTmp = false; ; )
			{
				stateTmp = GPIO_GetState(0, 14);
				GPIO_SetState(0, 0, stateTmp);
			}
		}
	}
#endif

#if 0
	//UART test
	{
		volatile uint8_t dataFromUart = 0;

		UART_DriverInit(0, 3000000, L8_BIT, ONE_BIT, NONE_PARITY);
		UART_Status uartStatus;

		for (;;)
		{
			uartStatus = UART_ReturnStatusRegister(0);

			if(uartStatus.TXRDY == 1)
			{
				UART_PutByteToTransmitter(0, 0xAA);
			}

			dataFromUart = 0;

			if(uartStatus.RXRDY == 1)
			{
				dataFromUart = UART_ReadByteFromTrasmitter(0);
			}
		}
	}
#endif

#if 0
	//SPI test
	{
		volatile uint8_t dataFromSpi = 0;
		volatile uint16_t counter = 0;

		SPI_DriverInit(0, SPI_CLK_IDLE_HIGH, SPI_CLK_TRAILING);
		SPI_Status spiStatus;

		for (;;)
		{
			SPI_PutByteToTransmitter(0, 0x20, SPI_CHIP_TXSSEL0_N, false, true);

			spiStatus = SPI_ReturnStatusRegister(0);
			for (;spiStatus.TXRDY == 0;)
			{
				spiStatus = SPI_ReturnStatusRegister(0);
				counter++;
			}

			SPI_PutByteToTransmitter(0, 0x21, SPI_CHIP_TXSSEL0_N, false, true);

			spiStatus = SPI_ReturnStatusRegister(0);
			for (;spiStatus.TXRDY == 0;)
			{
				spiStatus = SPI_ReturnStatusRegister(0);
				counter++;
			}

			SPI_PutByteToTransmitter(0, 0x22, SPI_CHIP_TXSSEL0_N, true, true);

			spiStatus = SPI_ReturnStatusRegister(0);
			for (;spiStatus.TXRDY == 0;)
			{
				spiStatus = SPI_ReturnStatusRegister(0);
				dataFromSpi = SPI_ReadByteFromTrasmitter(0);
				counter++;
			}

			ClockSleep(1);
		}
	}
#endif

#if 1
	//I2C test
	{
		uint8_t sendData[] = { 0x8F };
		uint8_t *dataBuffer = 0;

		I2C_DriverInit(0);

		ClockSleep(1);

		I2C_SendReadData(0, 0xD2, sendData, 1, 2);

		for(I2C_Status finishOperationFlag = I2C_SENDING;
				finishOperationFlag == I2C_WAITING_FOR_SEND
				|| finishOperationFlag == I2C_SENDING;)
		{
	    	finishOperationFlag = I2C_CheckStatus(0);
		}

	    dataBuffer = I2C_PointerToInternalReadBuffer(0);

	    ClockSleep(1);
	}
#endif
    // Force the counter to be placed into memory
    volatile static int i = 0 ;

    // Enter an infinite loop, just incrementing a counter
    while(1) {
        i++ ;
    }
    return 0 ;
}

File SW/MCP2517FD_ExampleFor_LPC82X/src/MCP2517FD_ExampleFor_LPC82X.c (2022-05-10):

/*******************************************************************************
Copyright (c) 2018 Microchip Technology Inc. and its subsidiaries.

Subject to your compliance with these terms, you may use Microchip software and
any derivatives exclusively with Microchip products. It is your responsibility
to comply with third party license terms applicable to your use of third party
software (including open source software) that may accompany Microchip software.

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
IN NO EVENT WILL MICROCHIP BE LIABLE FOR ANY INDIRECT, SPECIAL, PUNITIVE,
INCIDENTAL OR CONSEQUENTIAL LOSS, DAMAGE, COST OR EXPENSE OF ANY KIND WHATSOEVER
RELATED TO THE SOFTWARE, HOWEVER CAUSED, EVEN IF MICROCHIP HAS BEEN ADVISED OF
THE POSSIBILITY OR THE DAMAGES ARE FORESEEABLE. TO THE FULLEST EXTENT ALLOWED
BY LAW, MICROCHIP'S TOTAL LIABILITY ON ALL CLAIMS IN ANY WAY RELATED TO
THIS SOFTWARE WILL NOT EXCEED THE AMOUNT OF FEES, IF ANY, THAT YOU HAVE PAID
DIRECTLY TO MICROCHIP FOR THIS SOFTWARE.
 *******************************************************************************/

/*****************************************************************************************
 * Author of this source file: Adrian Chemicz
 * Code base on microchip example for MCP2517FD chip. Only few part of code is very
 * similar but I'm not a license expert so I copied Microchip header license from original
 * file. When this topic will be clarified file will be updated. If it will be possible
 * license will be changed to 3-Clause BSD License.
 *
 * This example present how initialize, send CAN data and receive CAN data via MCP2517FD
 * chip. Also was added information how debug simple problem with SPI connection.
 * Code use as systic timer so it should be very easy portable to other ARM microcontroller.
 *****************************************************************************************/

#include "../driver/canfdspi/drv_canfdspi_api.h"
#include "../driver/spi/drv_spi.h"
#include "chip.h"
#include "GPIO_Driver.h"

/*****************************************************************************************
 * Structures used to configure MCP2517FD
 *****************************************************************************************/
// Transmit FIFO channel
#define CAN_TX_FIFO CAN_FIFO_CH2

// Receive FIFO channel
#define CAN_RX_FIFO CAN_FIFO_CH1

// Maximal amount of test that TX fifo isn't full
#define MAX_TXQUEUE_ATTEMPTS 20

// CAN configuration object
CAN_CONFIG canConfig;

// Transmit objects
CAN_TX_FIFO_CONFIG canTxConfig;
CAN_TX_MSGOBJ canTxObj;

// Receive objects
CAN_RX_FIFO_CONFIG canRxConfig;
REG_CiFLTOBJ canFifoFilterObj;
REG_CiMASK canFifoMaskObj;

CAN_RX_MSGOBJ canRxMsgObj;
uint8_t canRxMsgPayload[MAX_DATA_BYTES];

// Comunication status flags and error counters which is get from CiTREC register
CAN_ERROR_STATE canErrorFlags;
uint8_t canTrasmitErrorCounter;
uint8_t canReceiveErrorCounter;

/*****************************************************************************************
 * Application variables
 *****************************************************************************************/
uint32_t canRxMessageCounter;
uint32_t interruptCounter;

/*****************************************************************************************
* InitCanFdChip() - initialize MCP2517FD chip to work with appropriate baudrate and mode.
* During initialization is also correctly configured RX and TX FIFO.
*
*****************************************************************************************/
void InitCanFdChip(void)
{
	// Reset device
	DRV_CANFDSPI_Reset(DRV_CANFDSPI_INDEX_0);

	// Enable ECC and initialize RAM
	DRV_CANFDSPI_EccEnable(DRV_CANFDSPI_INDEX_0);

	DRV_CANFDSPI_RamInit(DRV_CANFDSPI_INDEX_0, 0xff);

	// Configure device by set CiCON register
	DRV_CANFDSPI_ConfigureObjectReset(&canConfig);
	canConfig.IsoCrcEnable = 1;
	canConfig.StoreInTEF = 0;

	DRV_CANFDSPI_Configure(DRV_CANFDSPI_INDEX_0, &canConfig);

	// Setup TX FIFO by set CiFIFOCON register
	DRV_CANFDSPI_TransmitChannelConfigureObjectReset(&canTxConfig);
	canTxConfig.FifoSize = 7;
	canTxConfig.PayLoadSize = CAN_PLSIZE_64;
	canTxConfig.TxPriority = 1;

	DRV_CANFDSPI_TransmitChannelConfigure(DRV_CANFDSPI_INDEX_0, CAN_TX_FIFO, &canTxConfig);

	// Setup RX FIFO by set CiFIFOCON register
	DRV_CANFDSPI_ReceiveChannelConfigureObjectReset(&canRxConfig);
	canRxConfig.FifoSize = 15;
	canRxConfig.PayLoadSize = CAN_PLSIZE_64;

	DRV_CANFDSPI_ReceiveChannelConfigure(DRV_CANFDSPI_INDEX_0, CAN_RX_FIFO, &canRxConfig);

	// Setup RX Filter by set CiFLTOBJ0 register
	canFifoFilterObj.word = 0;
	canFifoFilterObj.bF.SID = 0xda;
	canFifoFilterObj.bF.EXIDE = 0;
	canFifoFilterObj.bF.EID = 0x00;

	DRV_CANFDSPI_FilterObjectConfigure(DRV_CANFDSPI_INDEX_0, CAN_FILTER0, &canFifoFilterObj.bF);

	// Setup RX Mask by set CiMASK0 register
	canFifoMaskObj.word = 0;
	canFifoMaskObj.bF.MSID = 0x0;
	canFifoMaskObj.bF.MIDE = 1; // Only allow standard IDs
	canFifoMaskObj.bF.MEID = 0x0;
	DRV_CANFDSPI_FilterMaskConfigure(DRV_CANFDSPI_INDEX_0, CAN_FILTER0, &canFifoMaskObj.bF);

	// Link FIFO and Filter by set CiFLTCON0 register
	DRV_CANFDSPI_FilterToFifoLink(DRV_CANFDSPI_INDEX_0, CAN_FILTER0, CAN_RX_FIFO, true);

	// Setup Bit Time
	DRV_CANFDSPI_BitTimeConfigure(DRV_CANFDSPI_INDEX_0, CAN_500K_2M, CAN_SSP_MODE_AUTO, CAN_SYSCLK_40M);

	DRV_CANFDSPI_ReceiveChannelEventEnable(DRV_CANFDSPI_INDEX_0, CAN_RX_FIFO, CAN_RX_FIFO_NOT_EMPTY_EVENT);
	DRV_CANFDSPI_ModuleEventEnable(DRV_CANFDSPI_INDEX_0, CAN_TX_EVENT | CAN_RX_EVENT);

	// Select Normal Mode
	DRV_CANFDSPI_OperationModeSelect(DRV_CANFDSPI_INDEX_0, CAN_NORMAL_MODE);
}
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

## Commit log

2021-12-10 Upload file for CANFD isolated board
    I this commit was uploaded all files necessary to create CAN-FD evaluation board
    [CANFD_OptoIsolationBoard.kicad_pcb, CANFD_OptoIsolationBoard.sch]
2022-03-09 Add files regarding to LPC82X EvalBoard
    [LPC82X_EvalBoard.kicad_pcb, LPC82X_EvalBoard.sch]
2022-04-02 Update quartz information
    Previous value of quartz was incorrect(50MHz) now value is correct(40MHz)
    [CANFD_OptoIsolationBoard.sch]
2022-04-02 Add file for board without optoisolation
    [CANFD_EvalBoard.kicad_pcb, CANFD_EvalBoard.sch]
2022-04-10 Add LPC82X Peripheral library
    I added library for LPC82X microcontroller which support GPIO, UART, SPI and I2C peripheral.
2022-04-19 Add logic analyzer dump
    Logic analyzer dump was gather from LPC11U24 microcontroller example
    [SPI_Command.csv]
2022-05-02 Add SPI settings screenshot
2022-05-08 Add file with Blender 3D model of all PCB
2022-05-08 Add connection schematic
